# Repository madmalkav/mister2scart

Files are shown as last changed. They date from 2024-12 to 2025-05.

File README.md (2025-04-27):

# Disclaimer

This device has been designed by someone that doesn't have a clue about electronics. If you decide to build it and use it, you do it on your own responisibility.

# MISTER2SCART

This PCB is designed to connect a MiSTer VGA and audio analog output to a SCART RGB device using standard VGA and SCART cables. It includes a switch to set the TV to 4:3 or 16:9, and a RCA connector for lightguns that may require it.

The device is designed for **RGB output only**, it will probably not work with composite or s-video signals.

The device expects **5V from VGA** pin 9, if you use it with a HDMI to VGA dongle in Direct Video, it may not work, as some of these dongles doesn't provide this voltage.

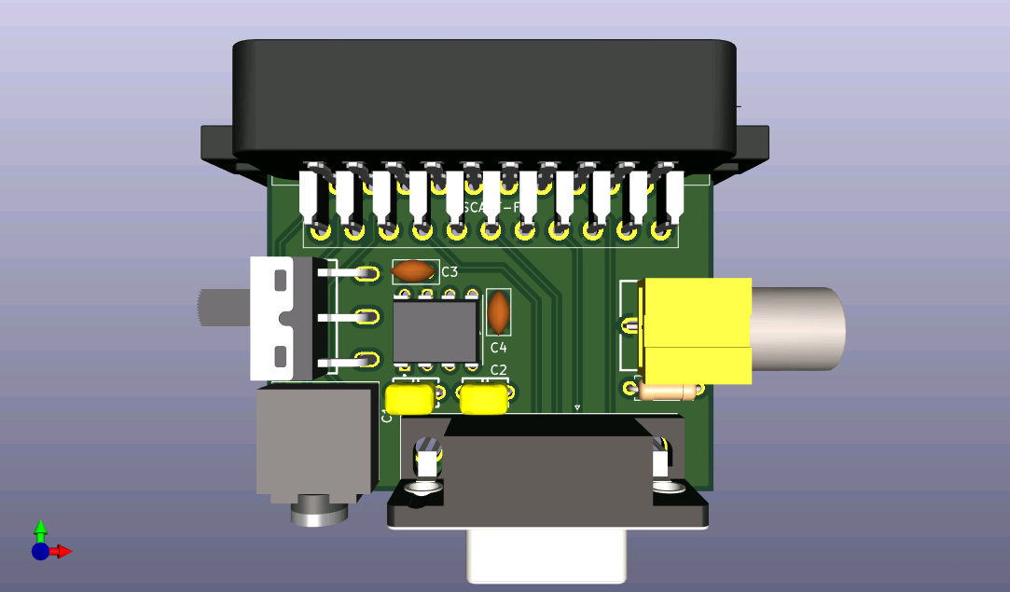
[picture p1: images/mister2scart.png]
3D preview


# Components

You are going to need:

- A female SCART connector like Ninigi SCART-17 , Kycon K-SCARTX-022 or similar. These are getting harder to find on the usual component shops but they are plenty available on Aliexpress.
- A female 3.5mm stereo jack with a footprint similar to SJ1-3523NG or similar. These are available both in component shops and Aliexpress.
- A female RCA connector, with footprint like  BOOMELE AV-5, Kobiconn 156-0098-E, Kycon KLPX-0848-2-BL and similars.
- A 470 Ohms, 1/4W resistor. The PCB is designed for a resistor of 6.3mm length.
- A sliding SPDT switch, I used SS12D10G6-WJ but again, anything with the same footprint should do.
- A MAX662ACPA IC, used to generate 12V for the 4:3 / 16:9 selection. 
- 2x MLCC 220nF 50V ±20% capacitors, with a 5.08mm distance between legs.
- 2x Tantalum 4.7uF 16V ±10%, with a distance of 2.54mm between legs.
- A VGA female connector, with a clearance from the pins to the edge of the PCB of ~3.08mm

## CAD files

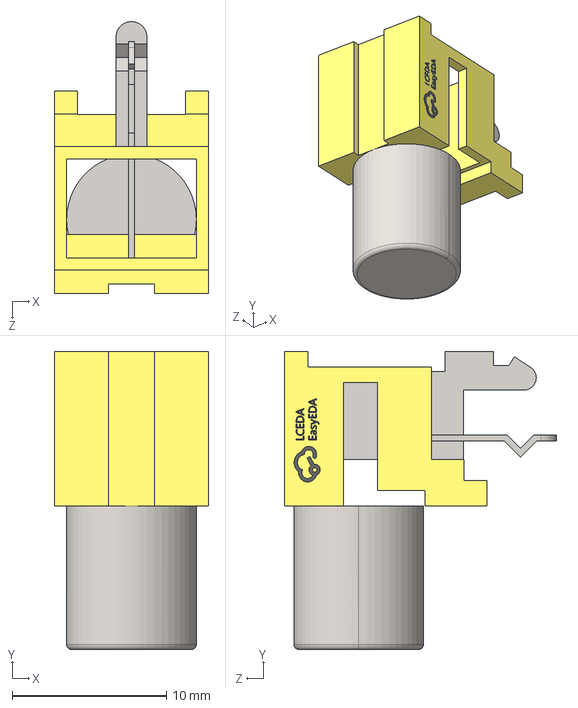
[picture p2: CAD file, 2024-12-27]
kicad/boomele_av-5/CONN-TH_AV-5.step
10.0 x 19.3 x 17.6 mm

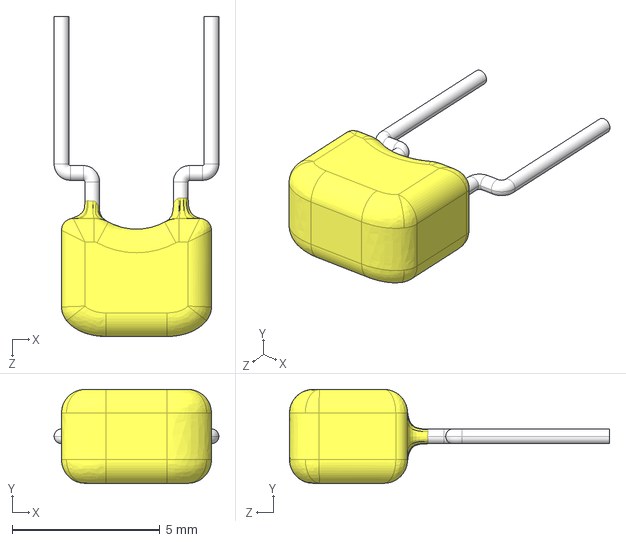
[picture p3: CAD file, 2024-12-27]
kicad/C322C224M5U5TA/CAP-TH_L5.1-W3.2-P5.08-D0.50.step
5.58 x 3.19 x 10.8 mm

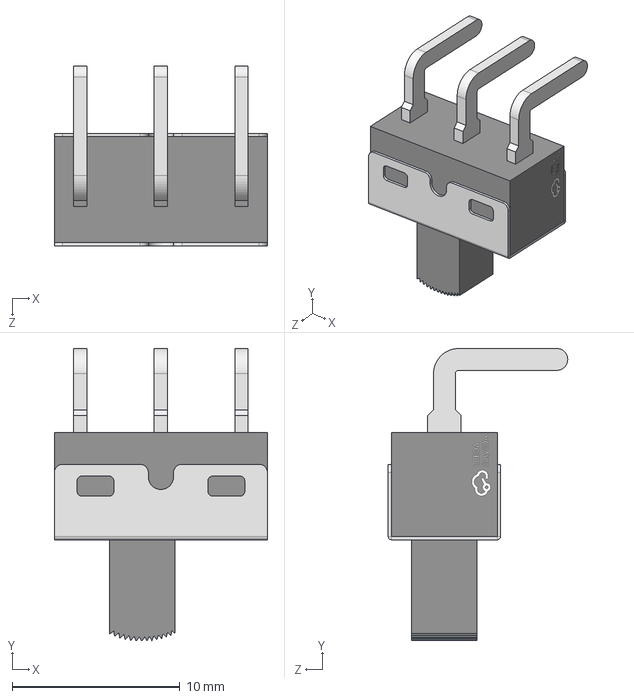
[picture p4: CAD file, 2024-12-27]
kicad/C7431059/SW-TH_3P-P4.80_HX-SS12D10G6-WJ.step
12.7 x 17.4 x 10.7 mm

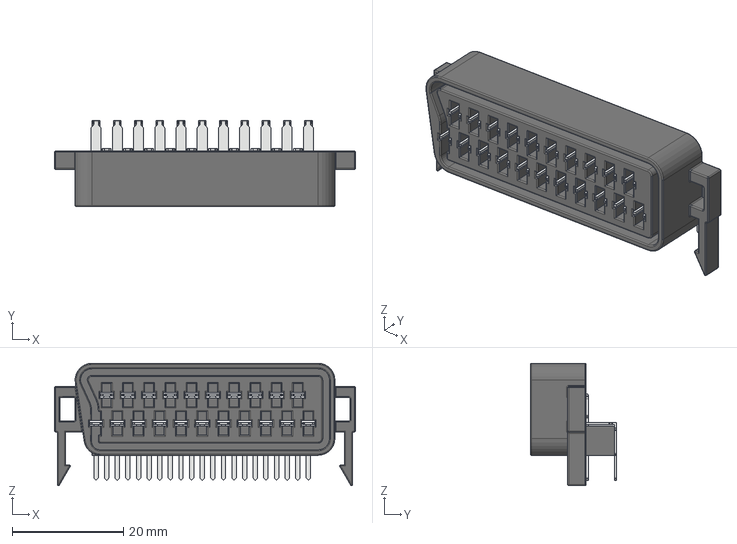
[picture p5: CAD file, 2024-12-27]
kicad/KYCON_SCART_K-SCARTX-022/KYCON_SCART_K-SCARTX-022_Horizontal.step
54.0 x 15.5 x 22.0 mm

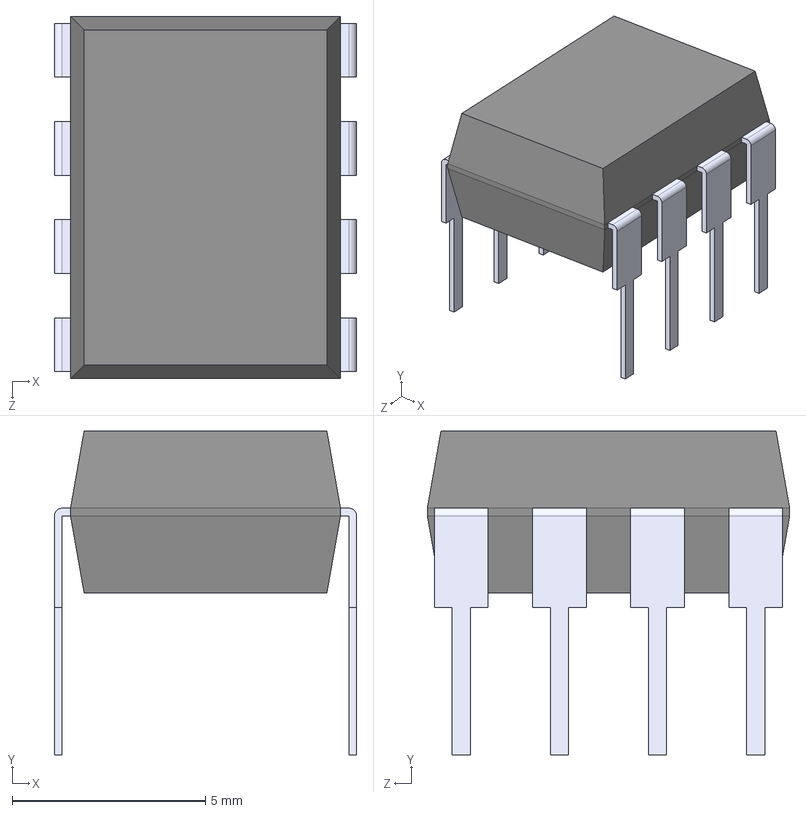
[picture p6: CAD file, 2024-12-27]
kicad/MAX662ACPA/MAX662ACPA_.step
7.82 x 8.38 x 9.38 mm

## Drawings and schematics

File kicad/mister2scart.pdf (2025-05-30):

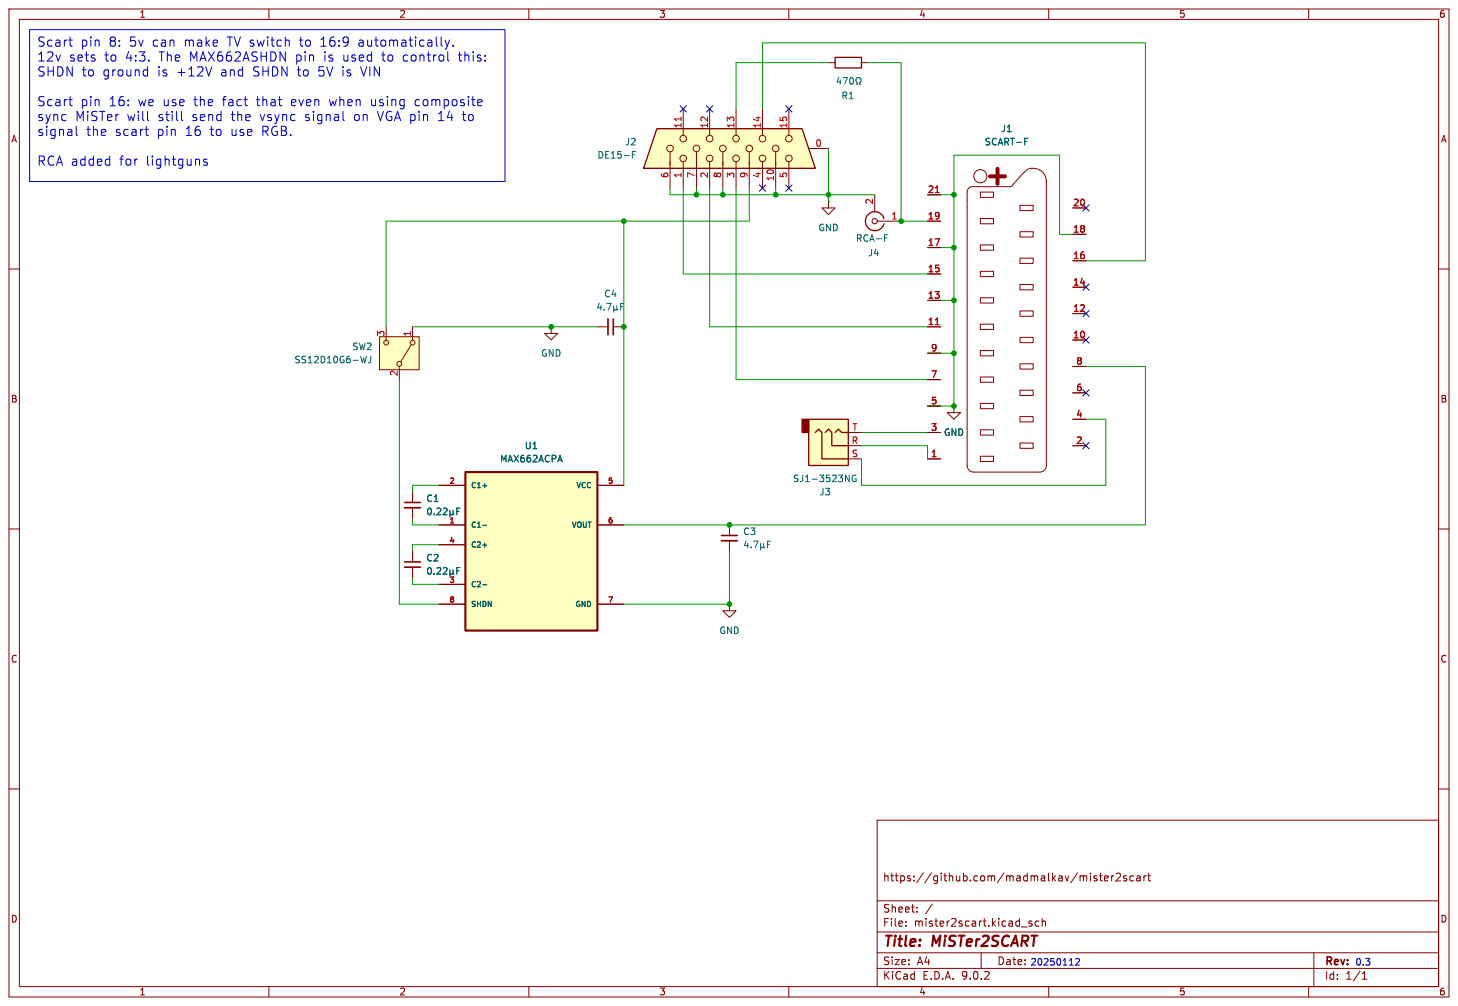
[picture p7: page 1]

RCA added for lightguns

File: mister2scart.kicad_sch Sheet: / https://github.com/madmalkav/mister2scart

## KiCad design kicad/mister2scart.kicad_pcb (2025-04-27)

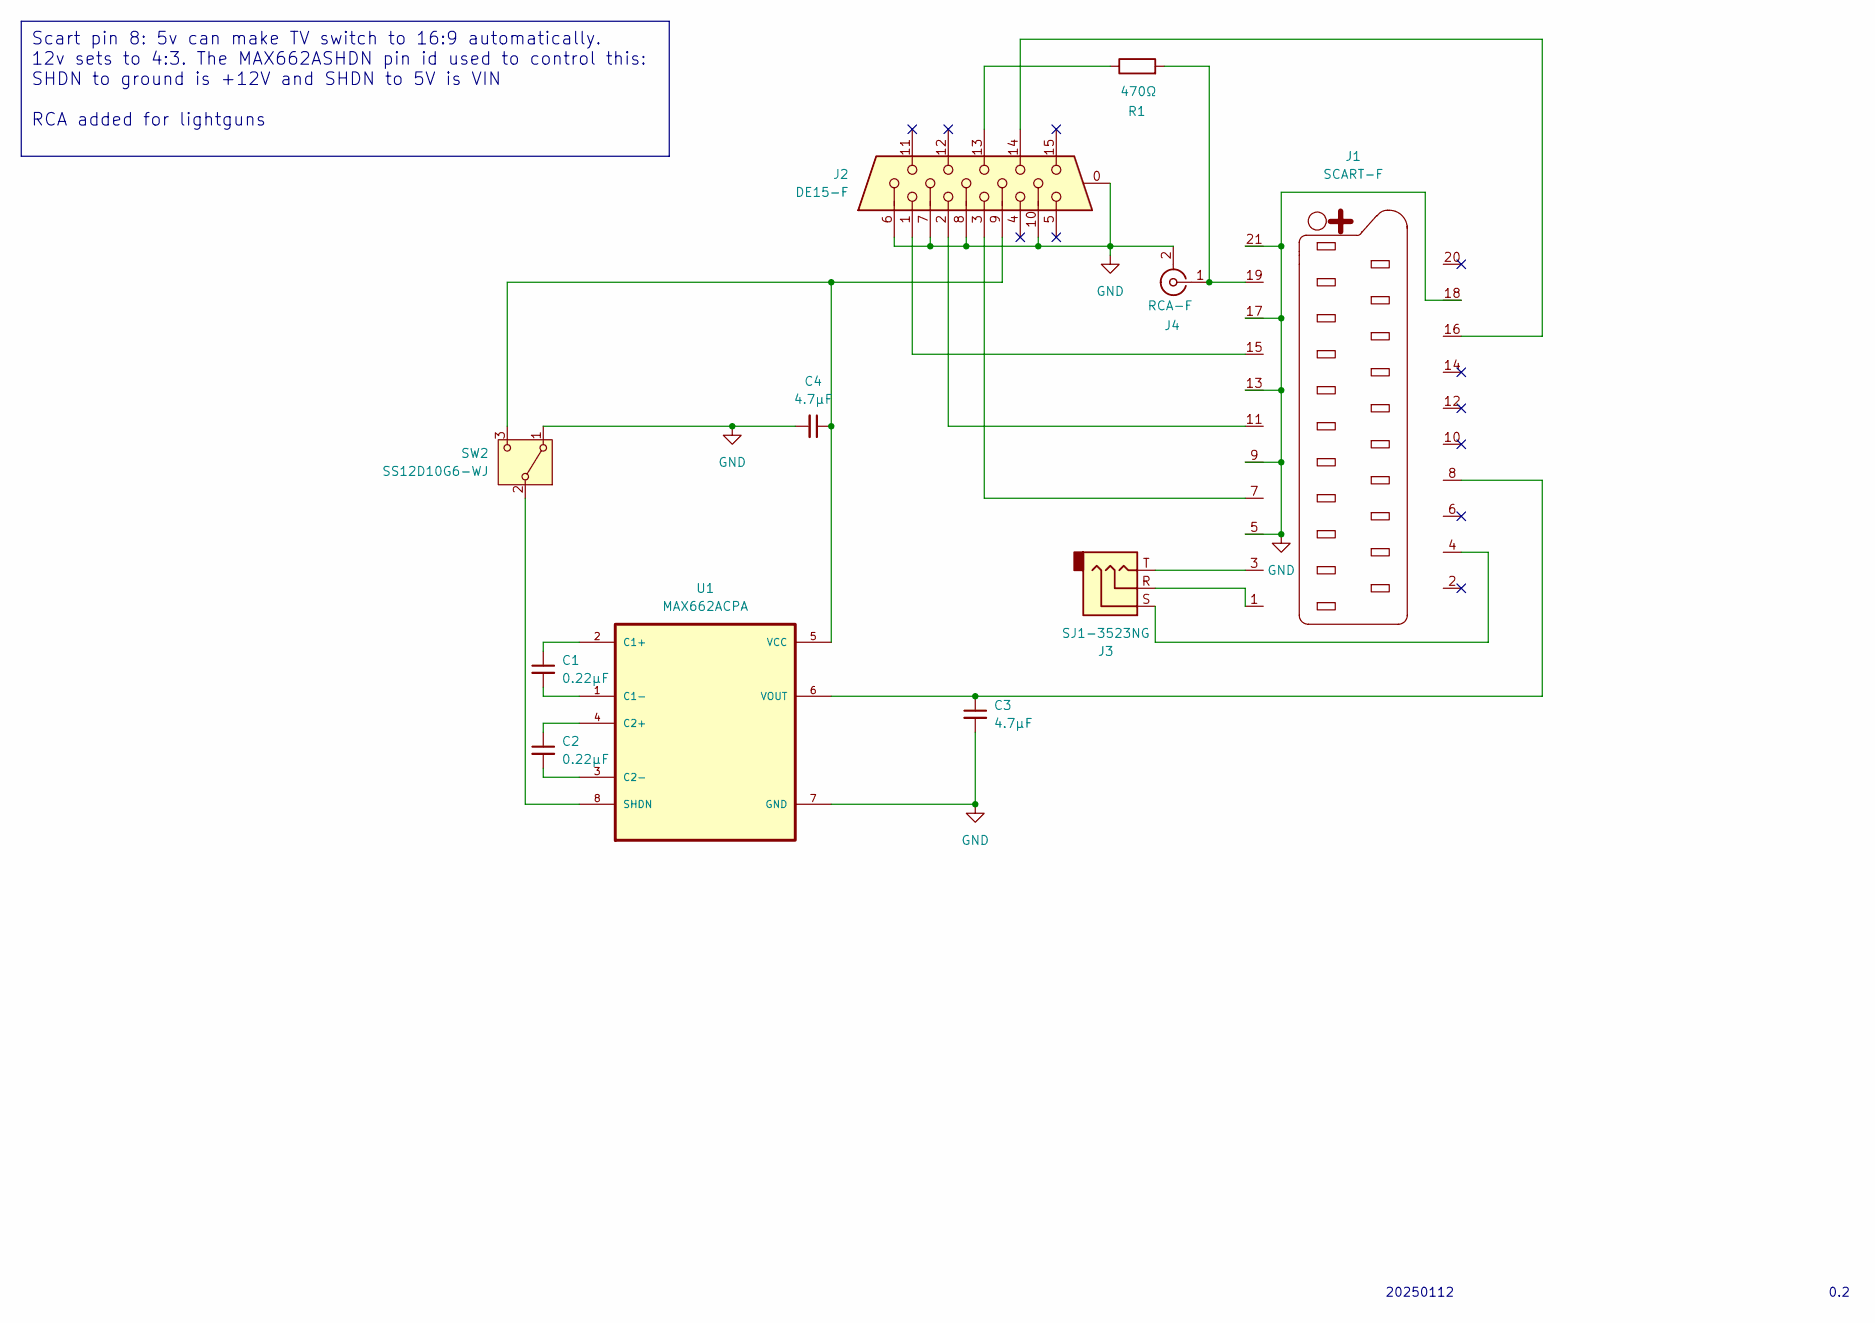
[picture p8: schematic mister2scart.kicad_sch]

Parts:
C1, C2: 0.22μF; CAP-TH_L5.1-W3.2-P5.08-D0.50; LCSC PN C1621936
C3, C4: 4.7μF; C_Disc_D5.0mm_W2.5mm_P2.50mm; LCSC PN C18164672
J1: SCART-F; KYCON_SCART_K-SCARTX-022_Horizontal
J2: DE15-F; DSUB-15-HD_Female_Horizontal_P2.29x1.90mm_EdgePinOffset3.03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; LCSC PN C3038673
J3: SJ1-3523NG; Jack_3.5mm_CUI_SJ1-3523N_Horizontal; LCSC PN C4992449
J4: RCA-F; CONN-TH_AV-5; LCSC PN C18080
R1: 470Ω; R_Axial_DIN0207_L6.3mm_D2.5mm_P10.16mm_Horizontal
SW2: SS12D10G6-WJ; SW-TH_3P-P4.80_HX-SS12D10G6-WJ; LCSC PN C19189125
U1: MAX662ACPA; DIP794W47P254L991H457Q8; LCSC PN C1355736

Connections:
GND: C3.2, C4.2, J1.5, J1.9, J1.13, J1.17, J1.18, J1.21, J2.0, J2.6, J2.7, J2.8, J2.10, J4.2 (Ext), SW2.1 (A), U1.7 (GND)
unnamed: J1.1, J3.R
unnamed: J1.3, J3.T
unnamed: J1.4, J3.S
unnamed: J1.7, J2.3
unnamed: C3.1, J1.8, U1.6 (VOUT)
unnamed: J1.11, J2.2
unnamed: J1.15, J2.1
unnamed: J1.16, J2.14
unnamed: J1.19, J4.1 (In), R1.2
unnamed: J2.13, R1.1
unnamed: SW2.2 (B), U1.8 (SHDN)
unnamed: C4.1, J2.9, SW2.3 (C), U1.5 (VCC)
unnamed: C1.1, U1.2 (C1+)
unnamed: C1.2, U1.1 (C1-)
unnamed: C2.1, U1.4 (C2+)
unnamed: C2.2, U1.3 (C2-)

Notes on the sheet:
20250112
0.2
Scart pin 8: 5v can make TV switch to 16:9 automatically. 12v sets to 4:3. The MAX662ASHDN pin id used to control this: SHDN to ground is +12V and SHDN to 5V is VIN RCA added for lightguns

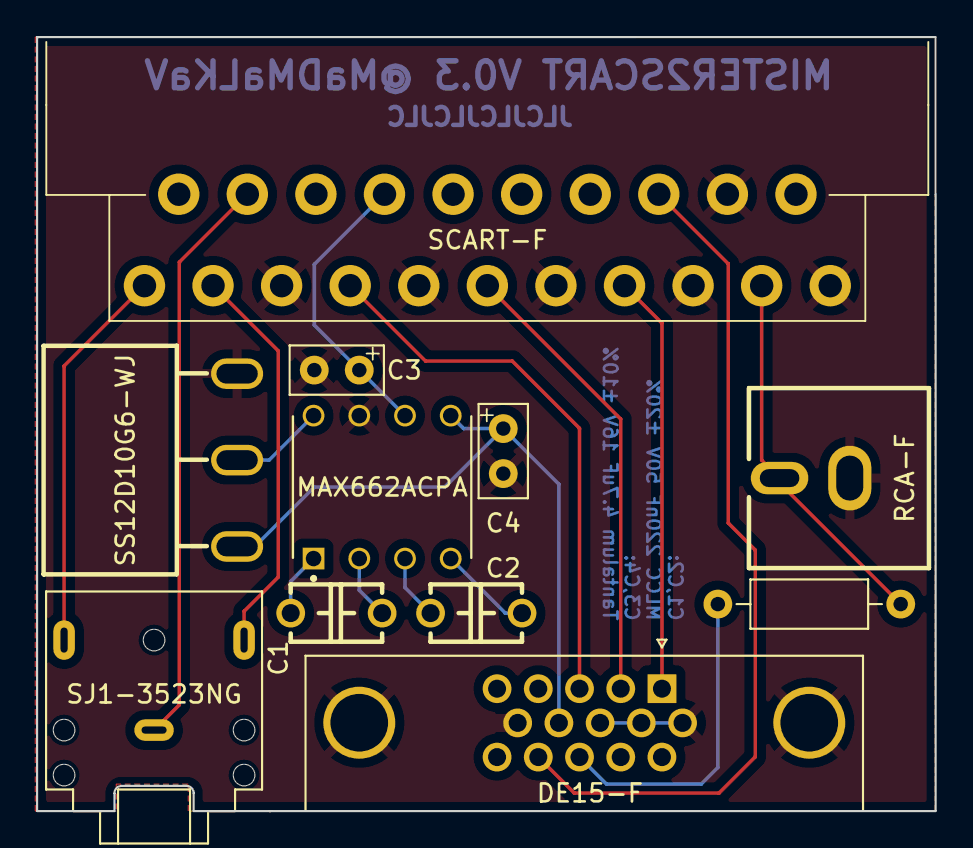
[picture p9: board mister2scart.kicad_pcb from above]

Board: 2 copper layers, 49.9 x 43.0 mm, 11 parts (0 on the bottom side), 17 nets.

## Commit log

2025-01-13 V0.2:
    - Corrected pinout of the SCART connection, as SCART to SCART cables have some pins crossed.
    - Marked polarity in the silkscreen for polarized capacitors
    - Increase footprint for resistor
    [mister2scart.kicad_pcb, mister2scart.kicad_sch]
2025-04-27 v0.3: fixed sync connector pinout
    [bom.csv, designators.csv, mister2scart.kicad_pcb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]
2025-05-30 Include schematic PDF
    [mister2scart.kicad_sch]
